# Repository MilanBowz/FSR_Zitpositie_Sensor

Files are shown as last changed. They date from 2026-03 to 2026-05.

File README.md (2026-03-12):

# FSR sensor: Zitpositie_Sensor

Piëzoresistieve (resistieve) dunnefilm druksensoren zijn varistoren (variabele weerstanden) in circuits. </br>

Wanneer de druksensor geen externe druk heeft, bevindt het circuit zich in een hoge impedantietoestand. Wanneer er externe druk op de sensor wordt uitgeoefend, neemt de weerstand af. Met behulp van een multimeter kan de weerstandswaarde direct worden afgelezen.

De weerstandswaarde verandert met de externe druk. De druk & weerstand staan in tegengestelde verhoudingen.

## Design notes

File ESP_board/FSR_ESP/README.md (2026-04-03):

# Resultaten FSR met simpele pull-down weerstand (10kE)

F: R = U/I
Rpulldown = 10kE | Rfsr (noload) > 2000 kE

## Als Rf/R2 niet ingedrukt

Vout ~= 0 V

## Als Rf/R2 ingedrukt
Vin >= Vout > 0 V 

## Testen met vaste gewichten Vin = 3.3V
Testmethode: Vcc = 3.3V altijd gewichten verwijderen voor volgend testresultaat</br>
Vout = Vcc * R0/(R0+Rs) = 3.3 * 10000/(10000+Rs)

### Sensor 2 Newton (~2kg)
Rfsr (noload) > 2000 kE

Gewicht (g) met weegschaal | Vout(min) (V) | Vout(rms) (V) | R_FSR (Ω)| voorwerp
------------------------|----------|---------|------------------------|----------|
0                       | 0        | 0 | >2000kE            | geen gewicht 
20                      | 1.44      | 1.52 | x           | glazen kurk
24                      | 2.00      | 2.08 | x          | glazen kurk + plastiek gadget
31                      | 2.24      | 2.32 | x           | glazen kurk + plastieke munt
35                      | 2.40      | 2.48 | x          | glazen kurk + plastieke munt + plastiek gadget
42                      | 2.56      | 2.64 | x          | glazen kurk + 2 plastieke munt
46                      | 2.64      | 2.72 | 3k          | glazen kurk + 2 plastieke munt + plastiek gadget
114                      | 2.72      | 2.84 | 500E         | glazen kurk + kaars 1
236                     | 2.96      | 3.04 | 300E          | glazen kurk + kaars 2
498 +20                     | 2.96      | 3.04 | 300E        | glazen kurk + kaars 3
?                    | 3.04      | 3.12 | x           | glazen kurk + max pressure human
...

Deze sensor werkt goed voor 20–500 g, maar verzadigt rond 3V (>500 g).

### Sensor 1 (0-150kg)
Rfsr (noload) > 2000 kE

Gewicht (kg) met weegschaal | Vout (V)  | R_FSR (Ω) | voorwerp
------------------------|-----------|-------------|----------|
0                       | 0         | >2000k          | geen gewicht / kurk
1.255                    | 0.036m     |  >2000k           | gymgewicht 1.25kg
2.324                    | 0.036m     | >2000k           | gymgewicht 2.5kg
3.579                    | 0.050m | >2000kE           | gymgewicht 2.5kg + 1.25
4.655                    | 0.100m | >2000k           | 2 x gymgewicht 2.5kg
5.910                    | 0.130m | >2000k          | 2 x gymgewicht 2.5kg + 1.25
26.000                    | 0.02 | 1500-1700k          | koeler  26kg </br> aan de 2000 kE grens|
... ||| metingen puur met multimeter
... ||| best > 30 kg om te meten
63.000 | x | 10k-12k | persoon x
... | x |  | persoon z
90.000                    | 3.15 | 200-450          | persoon y => max. gewicht |
...

**Vout = Vcc x R / (R + Rfsr)** </br>
2000kE : Vout ≈ 3,3/201 ≈ 0.016 V </br>
1500kE : Vout ≈ 3,3 x (10/(10 + 1500)) ≈ 0.02 V </br>
10kE : Vout ≈ 3,3 x (10/(10 + 10)) ≈ 1.5 V </br>
450E: Vout ≈ 3,3 x (10/(10+ 0,45)) ≈ 3,15 V

Deze sensor meet pas vanaf ~25 kg betrouwbaar, optimaal bereik voor 3.3V is 30–90 kg.

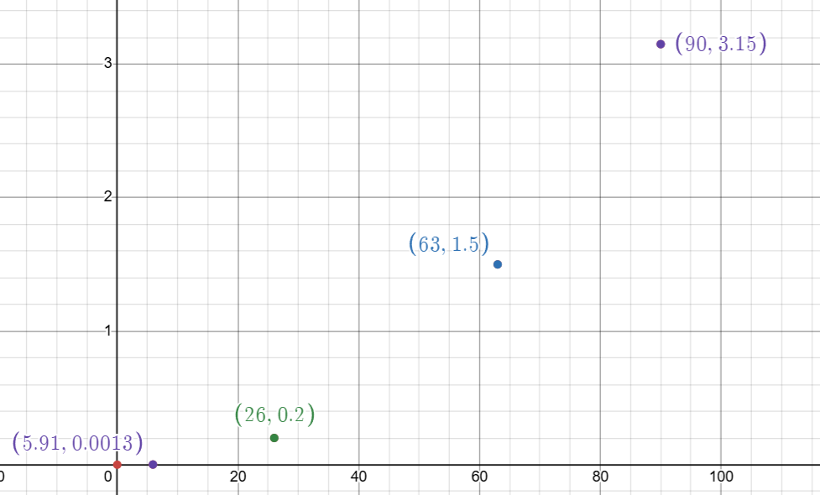
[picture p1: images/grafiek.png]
test


## Conclusies

FSR-sensoren zijn niet lineair: De weerstand daalt exponentieel met toenemende kracht, wat leidt tot een afnemende spanningsverandering bij hogere belastingen.

Dode zone bij lichte belasting – Beide sensoren vertonen vrijwel geen Vout voor gewichten onder ~10 kg (Sensor 1) of onder ~20 g (Sensor 2). Pas boven drempelwaarde treedt meetbare verandering op.

Grafiek toont typische FSR-kromme – Steile stijging in lage belasting, daarna afvlakking (verzadiging).

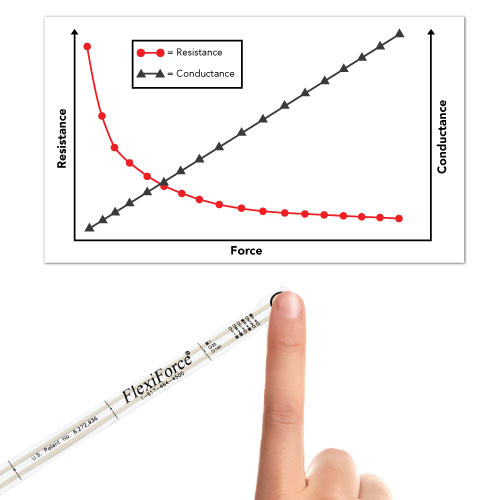
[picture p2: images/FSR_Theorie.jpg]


## Verdere stappen

1. Data doorgeven aan PC
    - Serieel (USB-UART) – Meest eenvoudig: stuur Vout-waarden als ASCII via Serial.print() naar PC.
    - ADC uitlezen (ESP32) – analoge pin, sample rate ≥ 10 Hz. (done)

2. Grafiek displayen (real-time of offline)

3. Zithouding herkennen via grafiekanalyse

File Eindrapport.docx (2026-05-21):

# Elektronische Systemen 2: FSR

Author | Milan Posman, Nick Driessen

Abstract

Dit project richt zich op het ontwikkelen van een systeem om zithouding en bewegingen op een stoel te detecteren met behulp van FSR-druksensoren. Het systeem meet de drukverdeling op de stoel om verschillende houdingen zoals rechtop zitten, onderuitgezakt zitten en verzitbewegingen te herkennen.

De FSR-sensoren worden strategisch op de stoel geplaatst en reageren op drukveranderingen tijdens het zitten. Tijdens een eerste test werd aangetoond dat het systeem onderscheid kan maken tussen verschillende zitposities en bewegingen. De sensoren werden gekalibreerd om nauwkeurige metingen mogelijk te maken.

Voor het eindproduct worden de sensoren discreet onder de stoelpoten geplaatst. De elektronica wordt in een kleine behuizing onder de stoel gemonteerd en kan op batterijen werken.

Het eindresultaat is een functioneel prototype dat real-time houdingsdetectie en bewegingsherkenning mogelijk maakt. De data kan lokaal worden weergegeven of draadloos worden doorgestuurd voor verdere analyse, met toepassingen in ergonomie en langdurige monitoring.

Content

# Intro

## Situering

De onderzoeksvraag: “Hoe kan een systeem op basis van FSR-druksensoren worden ontwikkeld en gevalideerd om zithouding (rechtop,onderuitgezakt,...) en bewegingen (verzitten , gewichtsverplaatsing,...) op een stoel te detecteren? ”

## Doelstellingen

Real-time houdingsdetectie mogelijk maken voor praktische toepassingen.

Onderscheid maken tussen verschillende zitposities.

# Materiaal & methodes

## Gebruikte technologie

- Bluetooth

## Hardware gebruikt ter ondersteuning

### Keuze sensor

Mogelijke sensoren om druk te meten:

- FSR sensor (Force Sensitive Resistor)
  - Weerstandswaarde verandert als er druk op komt
  - Goedkoop en eenvoudig te gebruiken
  - Minder nauwkeurig
  - Gebruikt voor: bedieningspanelen van medische apparatuur, op de dashboards van auto's en op de bedieningspanelen van industriële apparatuur
- Load cell
  - Zeer nauwkeurig
  - Complexer en duurder
  - Gebruikt bij weegschalen

Er is gekozen voor FSR-sensoren omdat:

- De eenvoud en lage kostprijs prioriteit hebben voor dit project.
- De lagere nauwkeurigheid is aanvaardbaar voor het detecteren van zithouding en bewegingen (discrete detectie, geen exacte gewichtsmeting nodig).
- De sensor eenvoudig kan worden uitgelezen met een microcontroller (geen extra versterker nodig).

Gebruikte FSR-sensoren:

  - FSR met 2 kg-limiet om werking makkelijk uit te testen
  - FSR van 150 kg-limiet om te gebruiken in eindproduct

### Ondersteunend materiaal

- Weerstand van 10kE om kortsluiting te voorkomen
- ESP32: microcontroller als FSR uitlezer en verzender via bluetooth.
- breadboard, jumperkabels, ... : voor het bouwen van prototypes.
- 3D printer voor FSR stabieler te kunnen testen

## Softwaretools gebruikt ter ondersteuning

- Visual Studio (PlatformIO) / Arduino IDE: programmeren en uploaden van ESP32-code.
  - BluetoothSerial.h library voor bluetoothcommunicatie op ESP32
- Thonny: visualisatie van waardes via dashboard op laptop
- Serial Monitor: debuggen van bluetooth-communicatie.

# Resultaten

## ESP32: uitlezen FSR-weerstand

FSR-sensoren zijn varistoren (variabele weerstanden) in circuits.

Wanneer de druksensor geen externe druk heeft, heeft de FSR een hoge weerstand. Wanneer er externe druk op de sensor wordt uitgeoefend, neemt de weerstand af. Met behulp van een multimeter, oscilloscoop of microcontroller kan de weerstandswaarde direct worden afgelezen.

FSR / Weerstand | ESP32 (zie afbeelding) | Multimeter-meting
FSR (Begin) | 3.3 V | Rfsr (noload) > 2000 kE Rfsr (fullload) ≃ 0 E
FSR (Einde) | GPIO34 / D34 (ADC1_CH6)
Weerstand (Einde) | GND | R = 10kE , deze weerstand is tegen kortsluiting

De weerstandswaarde verandert met de externe druk. De druk & weerstand staan in tegengestelde verhoudingen.

### Circuit zonder opamp

Voorbeeldcircuit in Multisim online (vervang potentiometer door FSR-weerstand):

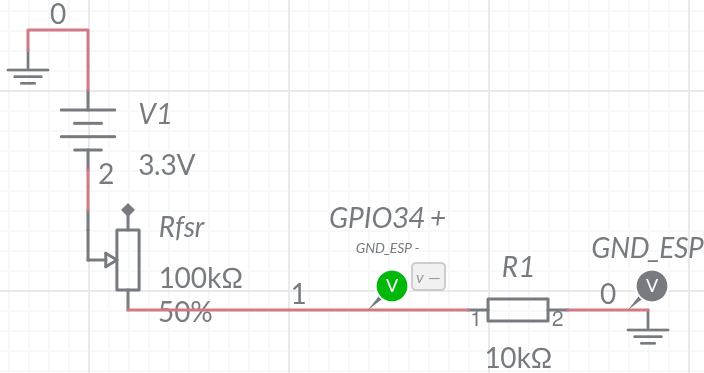
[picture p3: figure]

### Alternatief circuit met opamp: Transimpedance Amplifier

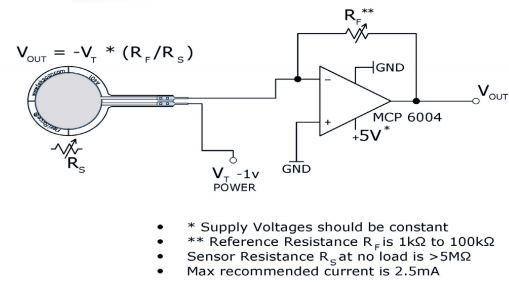
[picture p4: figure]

Een FSR-sensor met een transimpedance amplifier geeft een nauwkeuriger en meer lineaire eindmeting dan met een eenvoudige pull-downweerstand. Hierdoor is de gevoeligheid hoger en wordt de meting minder afhankelijk van variaties in de weerstand van de FSR.

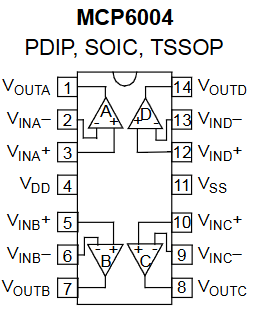
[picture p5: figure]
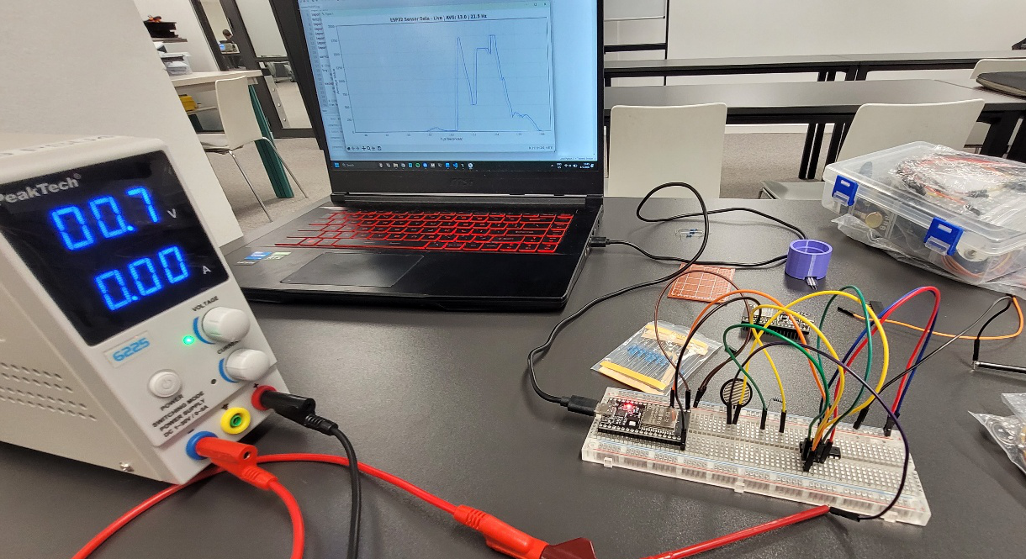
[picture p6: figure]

Nabouwen Transimpedance Amplifier met FSR sensor:

### Software

De software initialiseert de Bluetooth communicatie op een COM poort op Windows (11).

Softwarebenodigdheden:

- Arduino IDE / Visual studio code (PlatformIO)
- Blender om stabielere testopstelling te maken
- BluetoothSerial.h Arduino library
- Thonny editor voor pythoncode met:
  - matplotlib om resultaat te tonen in een grafiek
  - serial om te communiceren met de ESP32 via bluetooth

### 3D-Models

Deze modellen zijn ontworpen om veel stabielere resultaten te verkrijgen in tests door de FSR sensor vast te zetten in het groene model en een de objecten die gewogen worden op het paarse object (~ kurk) te plaatsen.

Het paarse object kan vervangen worden door een glazen kurk, maar daarvoor moet je voorzichtig zijn dat deze kurk niet te veel kan bewegen (kan voor verschillende metingen zorgen).

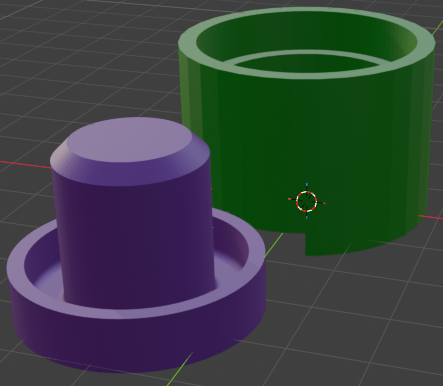
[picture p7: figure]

### Test: relatie tussen gewicht en voltage / weerstand

Deze tests werden uitgevoerd met de 3.3 V & GND van de ESP, maar de uitmeting van de voltage werd gedaan met een oscilloscoop voor Voltage en multimeter voor de weerstandsmetingen.

#### Test met 2kg FSR sensor

Het gewicht wordt hier gemeten met een keukenweegschaal.

Conclusie Sensor 2: Werkt goed tussen 20–500 g. Verzadigt rond 3 V bij belasting > 500 g.

Gewicht (g) | Vout(min) (V) | Vout(rms) (V) | R_FSR (Ω) | Object
0 | 0 | 0 | >2000kE | geen gewicht
20 | 1.44 | 1.52 | x | glazen kurk
24 | 2.00 | 2.08 | x | glazen kurk + plastiek gadget
31 | 2.24 | 2.32 | x | glazen kurk + plastieke munt
35 | 2.40 | 2.48 | x | glazen kurk + plastieke munt + plastiek gadget
42 | 2.56 | 2.64 | x | glazen kurk + 2 plastieke munt
46 | 2.64 | 2.72 | 3k | glazen kurk + 2 plastieke munt + plastiek gadget
114 | 2.72 | 2.84 | 500E | glazen kurk + kaars 1
236 | 2.96 | 3.04 | 300E | glazen kurk + kaars 2
498 +20 | 2.96 | 3.04 | 300E | glazen kurk + kaars 3
? | 3.04 | 3.12 | x | glazen kurk + max pressure human

Bij het herhaaldelijk meten van hetzelfde gewicht kunnen andere waarden optreden. Dit komt door de eigenschappen van FSR-sensoren. Deze zijn de belangrijkste om rekening mee te houden bij basisgebruik / -testen :

- Plaatsing v/h gewicht: dit beïnvloed de drukverdeling, wat een ander “path van least resistance” kan geven voor de FSR met als gevolg een andere weerstandswaarde.
- Snelheid van belasting (en ontlasting) kan meer/minder druk op de FSR zetten, wat een andere weerstandswaarde veroorzaakt.
- Belasting toevoegen op bestaande belasting t.o.v. herbeginnen met 0: bij belasting toevoegen is de weerstandsverandering kleiner dan eerst resetten naar 0.

#### Test met FSR sensor van 150kg

Het gewicht wordt hier gemeten met een weegschaal voor mensen.

Conclusie FSR 150 kg: Meet pas betrouwbaar vanaf ~25 kg.

Optimaal bereik bij 3,3 V voeding: 30–90 kg.

Gewicht (kg) | Vout (V) | R_FSR (Ω) | Object
0 | 0 | >2000k | geen gewicht / kurk
1.255 | 0.036m | | gymgewicht 1.25kg
2.324 | 0.036m | | gymgewicht 2.5kg
3.579 | 0.050m | | gymgewicht 2.5kg + 1.25
4.655 | 0.100m | | 2 x gymgewicht 2.5kg
5.910 | 0.130m | | 2 x gymgewicht 2.5kg + 1.25
26.000 | 0.02 | 1500-1700k | koeler 26kg aan de 2000 kE grens
... | | | metingen puur met multimeter best > 30 kg om te meten
63.000 | x | 10k-12k | persoon x
... | x | | persoon z
90.000 | 3.15 | 200-450 | persoon y => max. gewicht

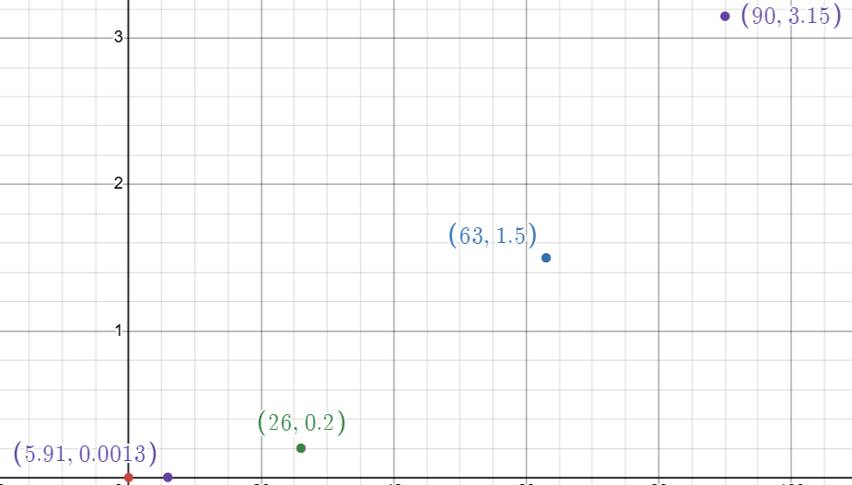
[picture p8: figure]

#### Conclusies uit testopstelling

FSR-sensoren zijn niet lineair: De weerstand daalt exponentieel met toenemende kracht, wat leidt tot een afnemende spanningsverandering bij hogere belastingen.

Dode zone bij lichte belasting – Beide sensoren vertonen vrijwel geen Vout voor gewichten onder ~10 kg (FSR 150kg) of onder ~20 g (FSR 2 kg). Pas boven drempelwaarde treedt meetbare verandering op.

Bij het herhaaldelijk meten van hetzelfde gewicht kunnen andere waarden optreden.

Deze zijn de belangrijkste om rekening mee te houden bij basisgebruik / -testen :

- Plaatsing v/h gewicht
- Snelheid van belasting (en ontlasting)
- Belasting toevoegen op bestaande belasting t.o.v. herbeginnen met 0

Grafiek toont typische FSR-kromme zoals in deze modelgrafiek:

- Steile stijging in lage belasting, daarna afvlakking (verzadiging).

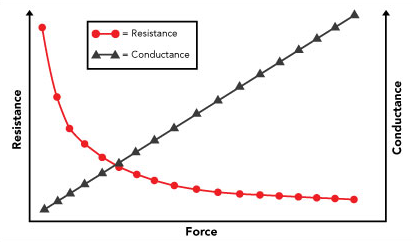
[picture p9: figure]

### Basiscode: Communicatie met PC via Bluetooth & tonen in een grafiek

De ESP32 verstuurt de gemeten sensorwaarden via Bluetooth naar een computer.

De Pythonsoftware:

- leest de seriële data uit;
- verwerkt de meetwaarden;
- toont de resultaten in real-time grafieken.

Hierdoor kunnen veranderingen in zithouding onmiddellijk zichtbaar gemaakt worden.

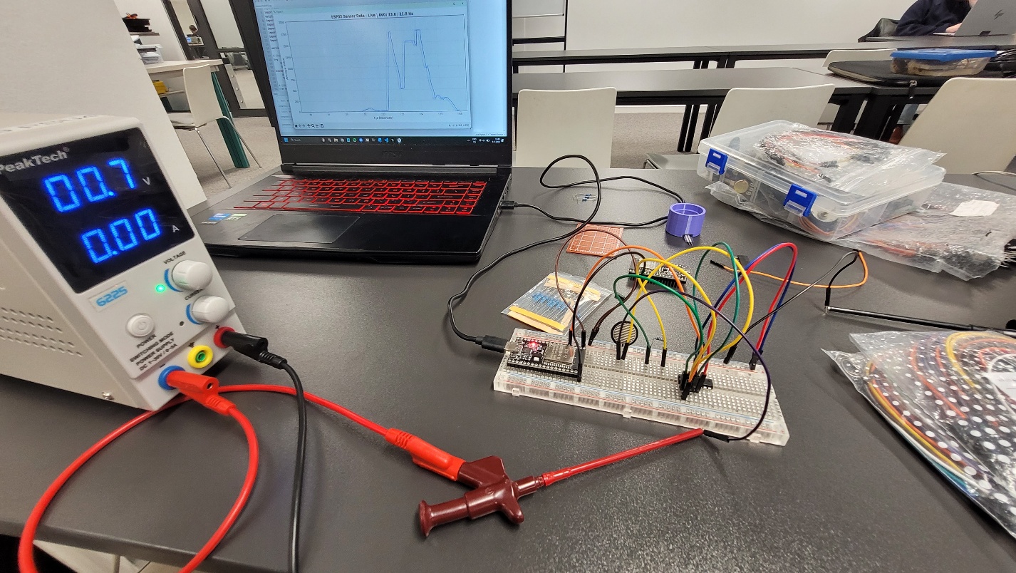
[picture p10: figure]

### Uitlezen van grafiek om zithouding & bewegingen te herkennen

Door meerdere FSR-sensoren onder een stoel te plaatsen kan de drukverdeling worden geanalyseerd.

## Mogelijke detecties

- Rechtop zitten
- Onderuitgezakt zitten
- Naar links of rechts leunen
- Verzitten
- Opstaan of gaan zitten

## Werking

Elke houding veroorzaakt een ander drukpatroon:

- meer druk achteraan → onderuitgezakt;
- ongelijke verdeling → leunen;
- snelle veranderingen → beweging.

Door deze patronen te analyseren kan het systeem houdingen herkennen.

# Mogelijke verbeteringen

## Hardware

- Meer sensoren toevoegen voor hogere nauwkeurigheid.
- Compactere behuizing ontwerpen.

## Functionaliteit

- Waarschuwingen bij slechte houding.
- Opslag van meetgegevens.

# Eindconclusie

In dit project werd een werkend prototype ontwikkeld dat zithouding en beweging detecteert met behulp van FSR-druksensoren en een ESP32-microcontroller.

Uit de experimenten bleek dat FSR-sensoren geschikt zijn voor het herkennen van drukveranderingen en houdingspatronen, ondanks hun beperkte nauwkeurigheid en niet-lineaire karakteristiek. De combinatie van een eenvoudige spanningsdeler, Bluetoothcommunicatie en real-time visualisatie maakte het mogelijk om verschillende zitposities en bewegingen te onderscheiden.

De 150 kg FSR-sensor bleek het meest geschikt voor toepassing in een stoel, aangezien deze ontworpen is voor hogere belastingen zoals het gewicht van een persoon. Hoewel de metingen variaties vertonen door drukverdeling en belastingshistoriek, zijn de resultaten voldoende betrouwbaar voor houdingsdetectie.

Het eindresultaat vormt een goede basis voor verdere ontwikkeling richting ergonomische monitoring, gezondheidsanalyse en slimme stoelsystemen.

Eindrapport Elektronische Systemen 2: Milan Posman, Nick Driessen

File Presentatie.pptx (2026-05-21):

## Elektronische Systemen FSR

## FSR sensor

Force-sensing resistors:
- Weerstand verlaagt met kracht
Intern:
- 2 geleidende lagen met daartussen
- drukgevoelig resistief materiaal

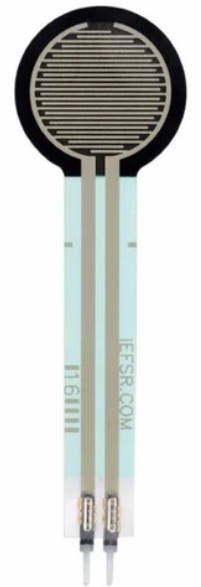
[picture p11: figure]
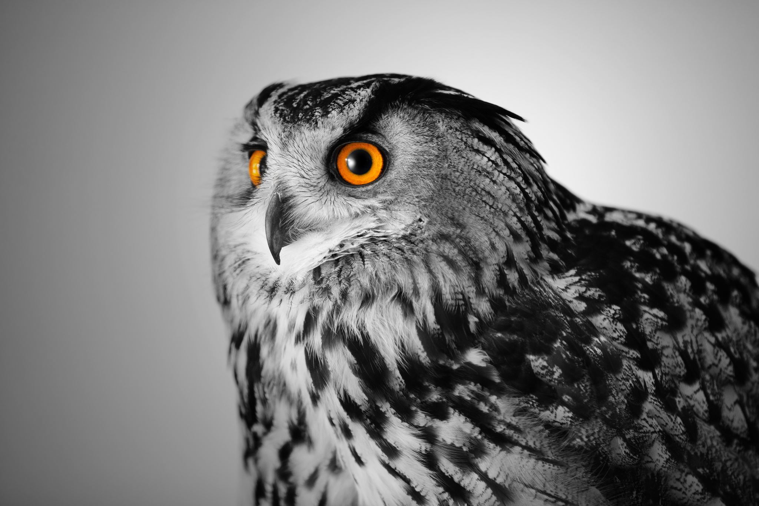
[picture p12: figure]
Black and white image of a hawk

## Onderzoeksvraag

“Hoe kan een systeem op basis van FSR-druksensoren worden ontwikkeld en gevalideerd om zithouding (rechtop,onderuitgezakt,...) en bewegingen (verzitten , gewichtsverplaatsing,...) op een stoel te detecteren? ”

## FSR-sensor met pull-down weerstand

- Gebruikt om relatie gewicht/voltage mee te testen


## FSR-sensor met pull-down weerstand

- Vergelijking met theorie

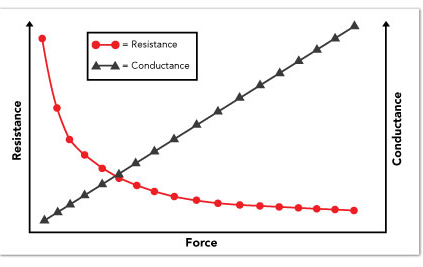
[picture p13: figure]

## Demo: FSR data tonen op laptop

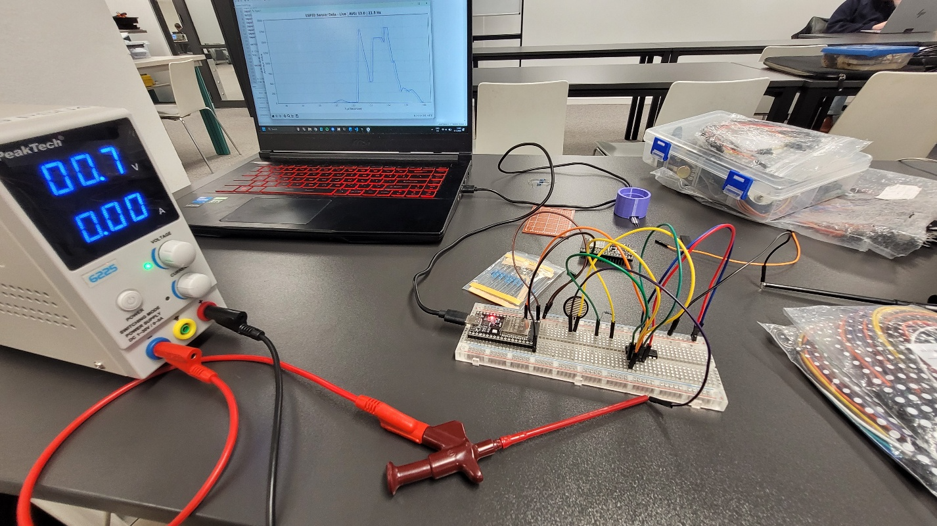
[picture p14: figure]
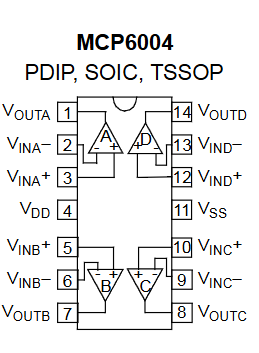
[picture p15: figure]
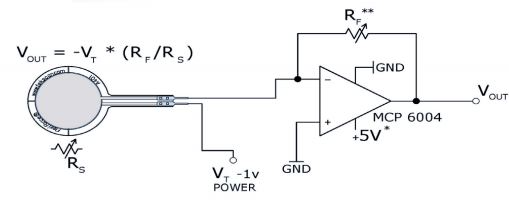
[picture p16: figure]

## Wat geleerd ? / uitdagingen

- Kiezen voor tijdbesteding / prioriteiten
- Zelfstandig taken opstellen
- Vertrouwbaar testen uitvoeren
  - Opstelling / 3D print

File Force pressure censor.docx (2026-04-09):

Sensorproject – Zitpositie detectie

1. Wat meten we en hoe

We willen meten of iemand correct op een stoel zit.
Dit doen we door de druk (gewicht) op de stoel te meten.

- We meten krachten tot ongeveer 150 kg
- De sensor zit onder het zitvlak
- Als iemand recht zit, is de druk gelijk verdeeld
- Als iemand scheef of onderuit zit, verandert de druk

Zo kunnen we zien of de zithouding goed is of niet.

2. Mogelijke sensoren

Er zijn verschillende sensoren om druk te meten:

- FSR sensor (Force Sensitive Resistor)
  - Weerstand verandert als er druk op komt
  - Goedkoop en eenvoudig te gebruiken
  - Minder nauwkeurig
- Load cell
  - Zeer nauwkeurig
  - Complexer en duurder

Wij gebruiken een FSR sensor van 150 kg, omdat die eenvoudiger is en voldoende voor ons doel.

Signaalverwerking

De FSR sensor werkt als een variabele weerstand:

- Meer druk → lagere weerstand
- Minder druk → hogere weerstand

We meten dit met een spanningsdeler:

- FSR + vaste weerstand
- De spanning ertussen gaat naar de ESP32

De ESP32 zet deze spanning om naar een digitale waarde.

3. Prototype

Schakeling

- FSR in serie met een vaste weerstand
- Middelpunt → analoge pin van de ESP32

Zo kunnen we de druk aflezen.

Testopstelling

We testen door:

- Gewichten op de sensor te plaatsen
- Op de stoel te zitten in verschillende houdingen

Bijvoorbeeld:

- Recht zitten → normale waarde
- Scheef zitten → andere waarde

Besluit

We gebruiken een FSR sensor met een ESP32 om druk te meten.
Dit is een eenvoudige oplossing die goed genoeg is om zithouding te detecteren, ook al is ze minder nauwkeurig dan een load cell.

Lab gewicht meten:

# Resultaten FSR met simpele pull-down weerstand (10kE)

Vout is de weerstand over R=10kE in serie met Rfsr

F: R = U/I

Rpulldown = 10kE | Rfsr (noload) > 2000 kE

## Als Rf/R2 niet ingedrukt

Vout ~= 0 V

## Als Rf/R2 ingedrukt

Vin >= Vout > 0 V

## Testen met vaste gewichten Vin = 3.3V

Testmethode: Vcc = 3.3V altijd gewichten verwijderen voor volgend testresultaat</br>

Vout = Vcc * R0/(R0+Rs) = 3.3 * 10000/(10000+Rs)

### Sensor 2 Newton (~2kg)

Rfsr (noload) > 2000 kE

Gewicht (g) met weegschaal | Vout(min) (V) | Vout(rms) (V) | R_FSR (Ω)| voorwerp

0 | 0 | 0 | >2000kE | geen gewicht

20 | 1.44 | 1.52 | x | glazen kurk

24 | 2.00 | 2.08 | x | glazen kurk + plastiek gadget

31 | 2.24 | 2.32 | x | glazen kurk + plastieke munt

35 | 2.40 | 2.48 | x | glazen kurk + plastieke munt + plastiek gadget

42 | 2.56 | 2.64 | x | glazen kurk + 2 plastieke munt

46 | 2.64 | 2.72 | 3k | glazen kurk + 2 plastieke munt + plastiek gadget

114 | 2.72 | 2.84 | 500E | glazen kurk + kaars 1

236 | 2.96 | 3.04 | 300E | glazen kurk + kaars 2

498 +20 | 2.96 | 3.04 | 300E | glazen kurk + kaars 3

? | 3.04 | 3.12 | x | glazen kurk + max pressure human

Deze sensor werkt goed voor 20–500 g, maar verzadigt rond 3V (>500 g).

### Sensor 1 (0-150kg)

Rfsr (noload) > 2000 kE

Gewicht (kg) met weegschaal | Vout (V) | R_FSR (Ω) | voorwerp

0 | 0 | >2000k | geen gewicht / kurk

1.255 | 0.036m | >2000k | gymgewicht 1.25kg

2.324 | 0.036m | >2000k | gymgewicht 2.5kg

3.579 | 0.050m | >2000kE | gymgewicht 2.5kg + 1.25

4.655 | 0.100m | >2000k | 2 x gymgewicht 2.5kg

5.910 | 0.130m | >2000k | 2 x gymgewicht 2.5kg + 1.25

26.000 | 0.02 | 1500-1700k | koeler 26kg </br> aan de 2000 kE grens|

... ||| metingen puur met multimeter

... ||| best > 30 kg om te meten

63.000 | x | 10k-12k | persoon x

... | x | | persoon z

90.000 | 3.15 | 200-450 | persoon y => max. gewicht |

**Vout = Vcc x R / (R + Rfsr)** </br>

2000kE : Vout ≈ 3,3/201 ≈ 0.016 V </br>

1500kE : Vout ≈ 3,3 x (10/(10 + 1500)) ≈ 0.02 V </br>

10kE : Vout ≈ 3,3 x (10/(10 + 10)) ≈ 1.5 V </br>

450E: Vout ≈ 3,3 x (10/(10+ 0,45)) ≈ 3,15 V

Deze sensor meet pas vanaf ~25 kg betrouwbaar, optimaal bereik voor 3.3V is 30–90 kg.


X = Gewicht in kg

Y = Voltage over R=10kE (Vout)

## Conclusies

FSR-sensoren zijn niet lineair: De weerstand daalt exponentieel met toenemende kracht, wat leidt tot een afnemende spanningsverandering bij hogere belastingen.

Dode zone bij lichte belasting: Beide sensoren vertonen vrijwel geen Vout voor gewichten onder ~10 kg (Sensor 1) of onder ~20 g (Sensor 2). Pas boven drempelwaarde treedt meetbare verandering op.

Grafiek toont typische FSR-kromme – Steile stijging in lage belasting, daarna afvlakking (verzadiging).

## Verdere stappen

1. Data doorgeven aan PC

- Serieel (USB-UART) – Meest eenvoudig: stuur Vout-waarden als ASCII via Serial.print() naar PC.

- ADC uitlezen (ESP32) – analoge pin, sample rate ≥ 10 Hz. (done)

2. Grafiek displayen (real-time of offline)

3. Zithouding herkennen via grafiekanalyse

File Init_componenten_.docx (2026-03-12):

Componenten:

- FSR-sensor: FSR02
- FSR-sensor: 0-150kg

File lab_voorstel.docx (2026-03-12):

Projectvoorstel: Drukgevoelige Zitpositie Sensor

1. Wat willen we meten?

We willen de drukverdeling op een stoel meten om de zithouding (rechtop vs. onderuitgezakt) te detecteren. Door de druk links en rechts te vergelijken, kunnen we afwijkingen vaststellen.

2. Welk sensorprincipe passen we toe?

We gebruiken twee FSR-sensoren (voorbeeld uit de link). Hun weerstand verandert naarmate de druk toeneemt. Deze weerstandsverandering zetten we om in een spanning.

3. Link met de vakinhoud?

Dit project past meerdere concepten toe:

Sensoren: De FSR zet fysieke druk om in een elektrisch signaal.

Rekstrookjes: weerstandsverandering door mechanische vervorming.

Brugschakeling: We plaatsen de sensoren in een Wheatstone-brug voor nauwkeurige meting.

Spanningsregelaar: Een regelaar zorgt voor de stabiele voeding die de sensor nodig heeft.

4. Huidig TRL-niveau?

TRL 2 (Technology Concept Formulated) . Het concept is bedacht, maar nog niet getest.

5. Te bereiken TRL-niveau?

TRL 4 (Component Validation in Laboratory Environment) . De sensoren worden in een labomgeving opgebouwd en getest.

6. Welke stappen nemen we?

Componenten: Twee FSR's, weerstanden, spanningsregelaar, breadboard en multimeter aanschaffen.

Ontwerp: Schema van de Wheatstone-brug met twee FSR's tekenen.

Bouw: Circuit opbouwen op breadboard met de spanningsregelaar.

Kalibratie: Sensorrespons meten door bekende gewichten te plaatsen.

Test: Ongelijkmatige druk uitoefenen (simulatie scheve zit) en het verschil meten.

Rapport: Bevindingen documenteren als bewijs van TRL 4.

Voorbeeld:

https://www.amazon.com.be/-/en/Sensitive-Resistance-Pressure-Resistor-Diameter/dp/B07PY443HS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

Milan Posman

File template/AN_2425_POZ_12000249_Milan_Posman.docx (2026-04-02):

# Project Onderzoek

Author | Milan Posman

Abstract

Dit project richt zich op het ontwikkelen van een communicatiesysteem op basis van LoRa E220-900T22D-modules, waarbij een microcontroller (ESP32,...) als zender en een Raspberry Pi 5 als ontvanger. Naast de configuratie en integratie van de LoRa-modules worden ook een NEO-6M GPS-ontvanger, DS18B20 temperatuursensor en een LDR toegepast.

De LoRa-communicatie is opgezet via UART met een baudrate van 9600 bps, waarbij M0 en M1 IO worden gebruikt om de E220-900T22D-module te kunnen configureren en gebruiken om data te verzenden en ontvangen. Met een 15 cm LoRa-gluestickantenne werd tijdens een veldtest een betrouwbaar maximaal bereik van 1,1 km gerealiseerd. Bij de configuratie wordt onder andere adressen, frequentiekanaal (868 MHz) en de transmissiemodus ingesteld.

Voor het eindproduct zijn alle componenten geïntegreerd in een behuizing. De verzender moet in een regenbestandige behuizing gesoldeerd op een gaatjesprint met batterijvoeding om buiten te kunnen fuctioneren. De ontvanger moet in een grote behuizing gevoedt door netstroom.

Het eindresultaat is een volledig functioneel prototype dat stabiele LoRa-communicatie, GPS-locatiebepaling, lichtintensiteit- en temperatuurmetingen combineert om te tonen in een dashboard en LCD dat met verdere iteraties online beschikbaar kan worden gemaakt,... .

Content

# Intro

## Situering

Dit project is voor het verkennen van goedkope draadloze IoT-communicatie, waarbij long-range datatransmissie centraal staat. LoRa-technologie wordt gebruikt om sensorwaarden over afstanden groter dan 1 km betrouwbaar door te sturen.

De onderzoeksvraag:

"Hoe kan een betrouwbaar long-range IoT-communicatiesysteem worden gerealiseerd met LoRa-technologie, waarbij (sensor)gegevens over afstanden groter dan 1 km worden verzonden?"

## Doelstellingen

Het doel van deze opdracht is het realiseren van een werkend long-range communicatiesysteem met LoRa-technologie. In de beginfase kozen we de benodigde componenten (LoRa-modules, zender, ontvanger, sensoren, antenne, ...).

De opdracht richt zich op:

- Het configureren en testen van de LoRa E220-modules.

- Het integreren van de sensoren (GPS-module (NEO-6M), temperatuursensor (DS18B20) en LDR).

- Het bouwen van een afgewerkt systeem door alle onderdelen in een passende behuizing te plaatsen.

- Het uitvoeren van praktijktests om bereik en betrouwbaarheid te evalueren.

Het uiteindelijke doel is een stabiel en volledig functioneel communicatiesysteem dat langeafstandsdata kan verzenden en ontvangen.

# Materiaal en methodes

## Gebruikte technologie

- LoRa (Long Range): draadloze communicatietechnologie voor lage datasnelheden over grote afstanden.

- UART / I2C / OneWire: communicatiestandaarden voor respectievelijk LoRa, LCD en temperatuursensor.

## Hardwaretools gebruikt ter ondersteuning

- Ebyte E220-900T22D: LoRa-transceivermodule gebaseerd op de LLCC68-chip.

- ESP32: microcontroller als verzender, met meerdere UART-poorten en laag energieverbruik.

- Raspberry Pi 5: single-board computer als ontvanger en data-verwerker.

- Neo-6M / NEO-M8N GPS Module: ontvangst van locatiegegevens.

- LDR (Light Dependent Resistor): meting lichtintensiteit

- DS18B20 Temperatuursensor: digitale temperatuursensor voor externe omgevingstemperatuur.

- Gaatjesprint, kabels, soldeerstation en behuizing : voor het bouwen van prototypes.

- Multimeter om correcte verbinding, kortsluitingen, ... te meten

## Softwaretools gebruikt ter ondersteuning

- Visual Studio (PlatformIO) / Arduino IDE: programmeren en uploaden van ESP32-code.

- Node-RED: visualisatie en besturing via dashboard van Raspberry Pi 5.

- Serial Monitor: debuggen van UART-communicatie.

- Ebyte Configuration Tool: controleren en configureren van LoRa-modules.

# Resultaten

## Verzender: FIXED_TRANSMISSION & E220-900T22D

Het verkennen van de E220-module en LoRa-technologie biedt een breed inzicht in de mogelijkheden van LoRa-communicatie. Dit hoofdstuk beschrijft de configuratie, werking en toepassing van de EBYTE LoRa E220-module in combinatie met de Wemos D1 Mini Pro als verzender en ESP32 als ontvanger.

De focus ligt op Fixed Transmission binnen het 868 MHz ISM-spectrum. Bij Fixed Transmission wordt elk bericht verzonden met een expliciet bestemmingsadres en kanaal.

### 1.1.1 GPIO -- Long range signal -- E220-900T22D

LoRa E220 | ESP32 | Wemos D1 Mini Pro | Opmerkingen
M0 | 21 / D21 | D7 | Normale modus (GND) / Configuratie modus (+3.3V)
M1 | 19 / D19 | D6 | Normale modus (GND) / Configuratie modus (+3.3V)
TX | RX2 / D16 | D2 | Communicatie UART
RX | TX2 / D17 | D1 | Communicatie UART
AUX | AUX: D22/23 | D5 | Busy status E220
VCC | 3.3 V - 5 V | 5 V | Voeding
GND | GND | GND | Aarde

Voorbeeldcode met FT_FIXED_TRANSMISSION zie: ```/Sender/Wemos_sendFixedTransmission.ino``` & ```Receiver/ESP32_receiveFixedTransmission/ESP32_receiveFixedTransmission.ino```

### 1.1.2 Software

De software initialiseert de UART-communicatie op 9600 bps en configureert de LoRa-module via AT-achtige commando’s die door de library worden afgehandeld.

Softwarebenodigdheden:

- Arduino IDE / Visual studio code (PlatformIO)

- LoRa_E220 Arduino library

- SoftwareSerial (voor Wemos D1 Mini Pro)

### 1.1.3 Configuratiemogelijkheden

Adressering

Binnen het LoRa E220-systeem beschikt elke module over een uniek logisch adres, bestaande uit twee delen:

- ADDH (Address High byte) +

- ADDL (Address Low byte)

Samen vormen deze bytes het node-adres ADDH + ADDL waarmee modules elkaar kunnen identificeren binnen een netwerk.

Adres van de zender

In deze configuratie werkt de Wemos D1 Mini Pro als zender:

- configuration.ADDH = 0x00;

- configuration.ADDL = 0x03 ;

Het volledige adres van de zender is daarmee 0x0003. Dit adres wordt intern gebruikt door de LoRa-module om de herkomst van verzonden berichten te identificeren.

Het zenderadres wordt niet meegegeven bij fixed transmissie, maar moet wel uniek zijn binnen het netwerk.

Adres van de ontvanger (Destination)

De ontvanger is geconfigureerd met:

- configuration.ADDH = 0x00 ;

- configuration.ADDL = 0x02 ;

Dit resulteert in het adres 0x0002. In de code van de verzender wordt dit aangeduid met:

``` #define DESTINATION_ADDL 2 ```

Bij Fixed Transmission wordt het bestemmingsadres expliciet opgenomen in elk verzonden bericht. Hierdoor accepteert uitsluitend de LoRa-module met adres 0x0002 het bericht; andere modules op hetzelfde kanaal negeren deze transmissie.

Relatie tussen zender en ontvanger

Samengevat:

- Zenderadres: 3 (0x0003)

- Bestemmingsadres: 2 (0x0002)

De zender (3) verstuurt data gericht naar de ontvanger (2) op een vast kanaal. Deze peer-to-peer-communicatie voorkomt dat andere nodes binnen hetzelfde frequentiekanaal de data verwerken.

Deze adresseringsmethode is essentieel voor schaalbare LoRa-netwerken waarin meerdere nodes gelijktijdig actief zijn zonder onderlinge interferentie.

Dat betekent dat enkel de ontvanger met een specifiek adres het bericht kan ontvangen en dus de andere apparaten geen tijd verspillen met onnodige berichten te ontvangen.

Kanaal en frequentie

Men gebruikt in de code:

- Kanaal: ```configuration.CHAN = 0x12```

- Frequentieband = basisfrequentie & kanaal ```850(.125) MHz + 0x12 MHz = 868(.125) MHz```

Het kanaal bepaalt de exacte frequentie binnen de toegestane ISM-band. Bij Fixed Transmission kan de channel voor een verzender en onvanger verschillen. De ontvanger kan bijvoorbeeld ```configuration.CHAN = 0x18;``` worden, terwijl de verzender 0x12 blijft.

Men moet deze code in de verzender als gevolg ook veranderen:

``` e220ttl.sendFixedMessage(0, DESTINATION_ADDL, 0x18, msg); ```

De functie ```e220ttl.sendFixedMessage()``` verzendt een bericht naar module met een specifiek adres en kanaal.

### 1.1.4 Algemene configuratiemogelijkheden

Transmission Mode: ```FT_FIXED_TRANSMISSION```

Ervoor zorgen dat Fixed Transmission geactiveert wordt in de module

RSSI (Received Signal Strength Indicator): ```DISABLED```

RSSI voegt extra informatie toe aan ontvangen berichten over de signaalsterkte. In deze configuratie is RSSI uitgeschakeld omdat:

- De focus ligt op basiscommunicatie en stabiliteit.

- Extra data-overhead wordt vermeden.

- Indien signaalkwaliteit of bereik in detail moet worden geëvalueerd, kan RSSI worden ingeschakeld voor onderzoeksdoeleinden.

LBT (Listen Before Talk): ```DISABLED```

LBT zorgt ervoor dat de module eerst controleert of het kanaal vrij is voordat er wordt uitgezonden. In dit onderzoek is LBT uitgeschakeld omdat:

- Het netwerk bestaat uit een beperkt aantal bekende nodes (4-6 verzenders, 1 ontvanger).

- Kanaalcongestie niet wordt verwacht. Continue en voorspelbare transmissie wordt verwacht.

WOR-periode (Wake-On-Radio) : ```2000 ms```

WOR bepaalt het interval waarin de module uit een laagvermogensmodus ontwaakt om te controleren op inkomende data.

WOR is met name enkel relevant voor batterijgevoede ontvangers en sinds enkel verzenders batterijgevoed worden kan dit standaard blijven.

### 1.1.5 Na configuratie

Na configuratie permanent opgeslagen wordt in het interne geheugen van de module wordt vervolgens:

- Bij het opstarten een testbericht verzonden.
- Worden elke 5 seconden berichten verzonden met een tijdstempel. Interessant voor te zien of er berichten verloren geraken.
- Kunnen handmatige berichten via de seriële monitor van de Wemos worden ingevoerd en verzonden.

## Prototype verzender 1: ESP32

### 1.1.6 Componenten

1. Gaatjesprint 50 * 70 mm

2. Microcontroller: ESP32

3. Stijve geleidende draad en jumperkabels

4. LoRa communicatie LoRa-module: E220

5. Multimeter om correcte verbinding en kortsluitingen te meten

6. Soldeerstation en bijhorende hulpmiddelen

### 1.1.7 Werkwijze: prototype 1 & 2

1. Solderen van female pinheaders

1. Eerst moet worden bepaald waar elk component wordt aangesloten aan de hand van het schema.
2. De soldering start bij de microcontroller, gevolgd door de LoRa-module.
3. Elke verbinding gecontroleerd met een multimeter om correcte verbinding en het ontbreken van kortsluitingen te verifiëren.

2. Bedrading met stijve geleidbare draad, begin met de aansluiting van Vcc & GND

3. Controle verbinding

Na het solderen wordt de verbinding tweemaal gecontroleerd. De controle focust zowel op het vermijden van kortsluitingen als op het garanderen van een betrouwbare elektrische verbinding.

1. ~ 5 minuten na het solderen
2. ~ 24 uur na het solderen, om mogelijke veranderingen van warmte of mechanische spanning te detecteren.

4. Extra isolatie

- Ter bescherming tegen waterschade en het risico op kortsluiting wordt een isolerende coating aangebracht.
- Tijdens dit proces worden gevoelige componenten tijdelijk verwijderd om beschadiging te voorkomen.

## Verzender prototype 2: Wemos D1 mini pro

### 1.1.8 Werkwijze

De werkwijze voor prototype 2 is identiek aan die van prototype 1, met als voornaamste verschil dat de ESP32 is vervangen door een Wemos D1 mini Pro. Daarnaast wordt gebruikgemaakt van een kleinere gaatjesprint met afmetingen van 40 × 60 mm.

Deze aanpassing heeft als doel te evalueren of het ontwerp kan worden verkleind naar een compacter formaat, zonder negatieve impact op de functionaliteit, betrouwbaarheid of soldeerkwaliteit van het prototype.

### 1.1.9 Conclusie

Uit prototype 2 blijkt dat het technisch mogelijk is om het ontwerp verder te verkleinen naar 40 × 60 mm.

Bij dit formaat wordt de integratie van andere componenten, zoals sensoren en batterij veel complexer. De beperkte beschikbare ruimte vereist een zeer doordachte plaatsing en soldering, waarbij manuele assemblage steeds moeilijker wordt.

Om deze reden is dit compact ontwerp beter geschikt voor machinale ontwikkeling, waar hogere precisie kunnen worden gegarandeerd.

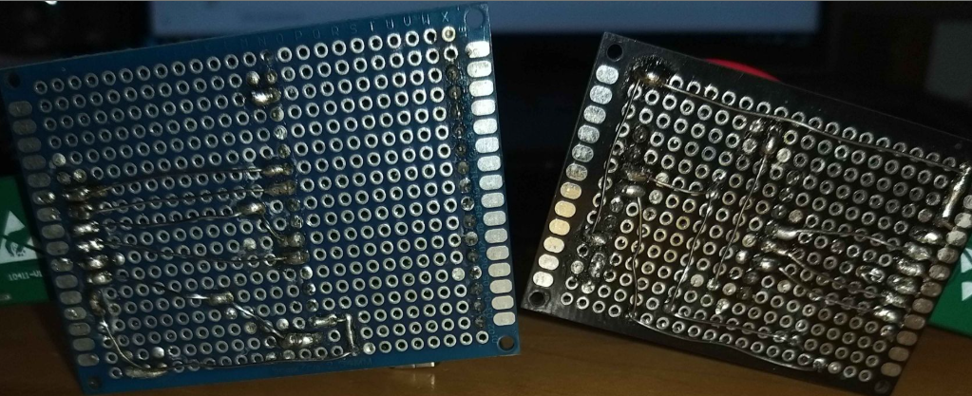
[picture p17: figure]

Solderen prototype 1 & 2: achterkant

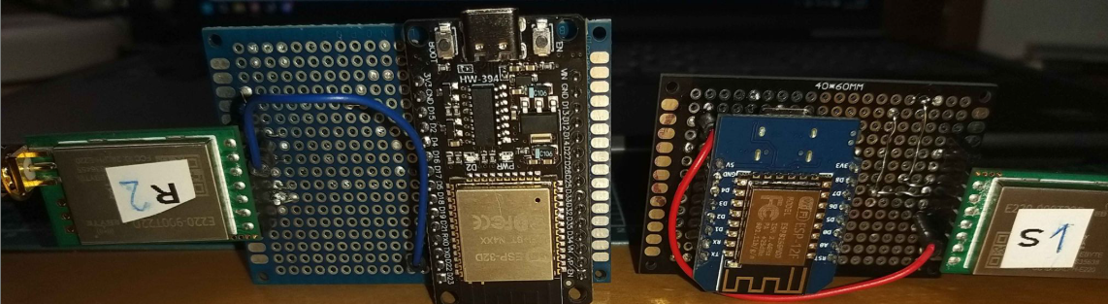
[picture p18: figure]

Solderen prototype 1 & 2: voorkant

Om deze 2 prototypes te testen kan het hoofdstuk FT_FIXED_TRANSMISSION geraadpleegd worden.

## Ontvanger (Raspberry Pi 5)

De Raspberry Pi 5 wordt in deze opstelling gebruikt als centrale ontvanger voor draadloze communicatie via de EBYTE LoRa E220-module. Naast het ontvangen van LoRa-berichten vervult de Raspberry Pi ook een verwerkings- en gebruikersinterface geprogrammeerd via Node-RED.

### 1.1.10 GPIO

De communicatie tussen de Raspberry Pi 5 en de LoRa E220-module verloopt via UART. Volgende tabel geeft een overzicht van de gebruikte GPIO-aansluitingen en hun functie.

LoRa E220 pin | Raspberry Pi 5 aansluiting | Opmerkingen (/dev/ttyAMA0)
VCC | 3.3 V – 5 V | Voeding
GND | GND | Aarde
TX | UART RX (GPIO 15) | UART-communicatie
RX | UART TX (GPIO 14) | UART-communicatie
M0 | GND / GPIO 21 | Normale modus (GND) / Configuratiemodus (+3.3 V)
M1 | GND / GPIO 20 | Normale modus (GND) / Configuratiemodus (+3.3 V)
AUX | GPIO 18 | Busy/statussignaal van de E220-module

Een LCD-scherm wordt aangesloten via het I2C-protocol om ontvangen gegevens visueel weer te geven.

LCD pin | Raspberry Pi 5 aansluiting | Opmerkingen
SCL | SCL (GPIO 3) | I2C communicatie: Serial Clock
SDA | SDA (GPIO 2) | I2C communicatie: Serial Data
GND | GND | Aarde
VCC | 5 V | Voeding

Een drukknop wordt gebruikt om de Raspberry Pi veilig in en uit te schakelen. Daarnaast geeft een LED de operationele status van het systeem en NodeRed weer.

Component | Raspberry Pi 5 aansluiting | Opmerkingen
LED + | GPIO 18 | Statusindicatie: Pi actief en Node-RED operationeel (met serieweerstand)
LED − | GND | Aarde LED
Button 0 | GPIO 17 & J2 | GPIO x voor software-shutdown, J2 voor hardware power control
Button 1 | GND (J2 / overige GND) | Aarde knop (normaal open drukknop)

### 1.1.11 Enable UART & I2C

Om seriële communicatie via UART en I2C mogelijk te maken, dienen deze geactiveerd te worden via de `Interfacing Options` van raspi-config.

Open de Raspberry pi configuratie met het commando ``` sudo raspi-config```

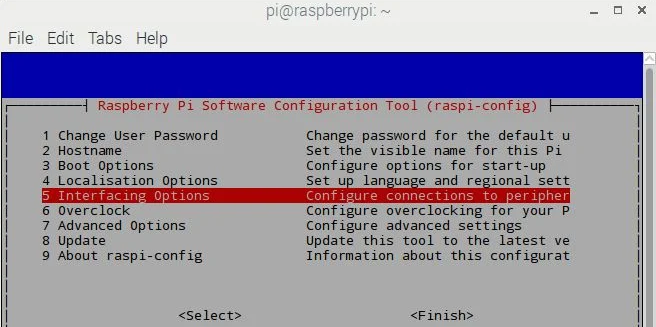
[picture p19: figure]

Configureer de volgende opties:

- Serial Port

- Login shell over serial: Disabled

- Serial port hardware: Enabled

- I2C: Enabled

Bevestig de wijzigingen en herstart de Raspberry Pi.

### 1.1.12 Controle activatie UART via configuratiebestand

Om te testen dat seriële communicatie via UART geactiveerd is waardoor seriële communicatie via `/dev/ttyAMA0` mogelijk wordt, kan in dit configuratiebestand van de Raspberry Pi gekeken worden.

Aan het einde van `/boot/firmware/config.txt` zal de volgende configuratie aanwezig zijn:

```

[all]

dtparam=uart0=on

```

### 1.1.13 Autostart Node-RED

Om Node-RED automatisch te starten bij het opstarten van de Raspberry Pi en het dashboard fullscreen weer te geven, wordt gebruikgemaakt van een shellscript en een `.desktop`-bestand.

Shellscript (`nodered_autostart.sh`)

```

sudo systemctl stop nodered.service;

sudo systemctl start nodered.service;

sleep 5;

chromium --kiosk --password-store=basic "http://127.0.0.1:1880/dashboard"; # open in browser

```

De eerste twee commando’s herstarten Node-RED. Dit zorgt ervoor dat Node-RED zich steeds in een bekende en stabiele toestand bevindt bij het opstarten van het systeem.

Vervolgens wordt er vijf seconden gewacht om te garanderen dat Node-RED volledig is opgestart voordat het dashboard wordt geopend.

Ten slotte wordt Chromium gestart in kioskmodus, waarbij het Node-RED dashboard automatisch fullscreen op het aangesloten beeldscherm wordt weergegeven. Hierdoor is het systeem geschikt voor visualisatie- of monitoringtoepassingen.

Autostart-configuratie (`~/.config/autostart/red.desktop`)

```

[Desktop Entry]

Type=Application

Name=Node-RED Autostart

Exec=<script-location>/nodered_autostart.sh

X-GNOME-Autostart-enabled=true"http://127.0.0.1:1880";

```

Het .desktop-bestand in `~/.config/autostart/` zorgt ervoor dat het shellscript automatisch wordt uitgevoerd zodra de grafische desktopomgeving van de Raspberry Pi is geladen.

De parameter `Exec` verwijst naar de locatie van het shellscript `nodered_autostart.sh`, terwijl `X-GNOME-Autostart-enabled=true` aangeeft dat deze applicatie automatisch wordt opgestart.

### 1.1.14 Controle van autostart

```

chmod +x red.desktop;

sudo reboot;

```

Door het .desktop-bestand uitvoerbaar te maken en het systeem te herstarten, kan de correcte werking van de autostart worden gevalideerd.

Na het herstarten start Node-RED automatisch en wordt het dashboard automatisch in kioskmodus weergegeven.

### 1.1.15 Test Configuratie & Communicatie met E220 (python)

Voor de configuratie en werking van de LoRa-module wordt UART gebruikt in combinatie met M0, M1 en AUX. Door deze signalen correct aan te sturen kan dynamisch worden gewisseld tussen configuratiemodus (AT-commands) en normale transmissiemodus.

Om het wisselen tussen configuratie- en transmissiemodus mogelijk te maken, worden M0 & M1 softwarematig aangestuurd. AUX wordt gebruikt als indicator wanneer de module bezig is.

Voor meer informatie zie ook handleiding E220-xxxTxxx : 5.2 AUX Timing, 7. AT Commands

Pseudocode voor configuratie van receiver:

1. M0 & M1 : 3.3 V / HIGH ( Configuration / Sleep mode )

2. Wacht tot AUX uitgang = HIGH ( E220 niet bezig )

3. Verzend @-command ( UART )

4. Wacht tot AUX = HIGH

5. Lees alles wat E220 beantwoordt ( UART )

6. Stap 3 OF exit config M0 & M1 : GND ( Transmission mode )

7. Wacht tot AUX = HIGH

8. Ontvang LoRa berichten …

Het volledig Python-codevoorbeeld voor de ontvanger is terug te vinden in:

`Receiver/reset_config_pi5/config+reset.py`

Belangrijke functies in de code:

- `enter_at_mode()` / `exit_at_mode()`

Wisselen tussen configuratie- en transmissiemodus via GPIO. (at-mode = configuratiemodus)

- `wait_aux_ready()`

Blokkering wanneer de module bezig is om timingproblemen te vermijden.

- `send_at_command()`

Verzenden en uitlezen van AT-commando’s via UART in configuratiemodus.

- `receive_data()`

Uitlezen van ontvangen in transmissiemodus.

## Eindproduct ontvanger: Raspberry Pi met Node-RED

### 1.1.16 Installatie en gebruik van Node-RED

Voor de installatie van Node-RED wordt de officiële gids gevolgd: Node-RED Getting Started – Local (https://nodered.org/docs/getting-started/local).

Met een Linux-command (Raspberry Pi,...) kan Node-RED geïnstalleerd worden:

```sudo npm install -g --unsafe-perm node-red``` # In Windows wordt sudo niet gebruikt.

Na installatie kan Node-RED gestart worden via: ```node-red```

Node-RED kan projecten (flows) exporteren in het .json-formaat, deze kunnen worden geïmporteerd door anderen. Indien het apparaat zich in een netwerk bevindt, kunnen anderen via de website van Node-RED toegang krijgen tot de flows voor controle of aanpassingen.

### 1.1.17 Communicatie met LoRa-module via UART

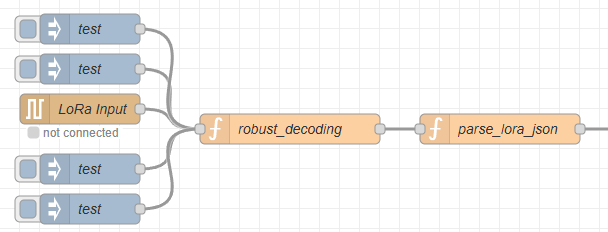
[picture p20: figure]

UART Communicatie `LoRa Input`

Voor de communicatie tussen Node-RED en de E220-module wordt een `Serial In` node gebruikt. Deze node leest inkomende gegevens via UART van de LoRa-module.

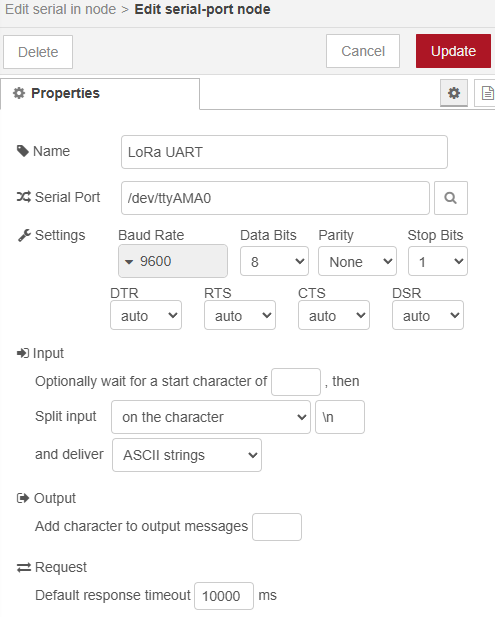
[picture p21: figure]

De `seriële poort` wordt `/dev/ttyAMA0` en is de UART-interface via de GPIO pinnen van de Raspberry Pi 5.

Aangezien de Raspberry Pi 5 meerdere UART-poorten heeft, kan een andere seriële poort geselecteerd worden indien er geen data wordt ontvangen. `/boot/firmware/config.txt` kan geraadpleegd worden om de correcte poort te vinden.

`Baud-rate 9600` is vastgelegd door de E220-module.

`Data Bits: 8` is de standaardinstelling voor UART communicatie.

`Geen pariteitscontrole` is de standaardinstelling voor UART communicatie.

`Stop Bits: 1` is de standaardinstelling voor UART communicatie.

UART-data omvormen `Robust decoding`

Voor het omvormen van UART-data wordt een `function` node gebruikt. Deze node zet bytegegevens om naar een leesbaar tekstformaat, zodat verdere verwerking en visualisatie mogelijk worden.

let text;

try {

text = msg.payload.toString('utf8'); // decode bytes

} catch (e) {

text = JSON.stringify(msg.payload); // fallback

}

msg.payload = text;

return msg;

Omdat niet alles naar `UTF-8` omgevormd kan worden (binaire data, transmissiefouten, ...), wordt een fallback-mechanisme gebruikt om de payload alsnog te tonen als `JSON`-data, waardoor debuggen mogelijk blijft.

Dataverwerking `parse_lora_json` voor weergave

Deze functie-node verwerkt de eerder gedecodeerde UART-data en zet deze om naar een object dat eenvoudig te gebruiken is in Node-RED.

De identificatie van het apparaat (`device`) en locatiegegevens (`lat, lon, alt, sats`) worden gebruikt in één overzichtelijke object die op een dashboard getoond kan worden. Daarnaast wordt de temperatuur (`tempC`) gecontroleerd. Als `tempC` een geldig getal is, wordt deze afgerond op twee cijfers na de komma en opgeslagen voor weergave.

### 1.1.18 Shutdown & Startup

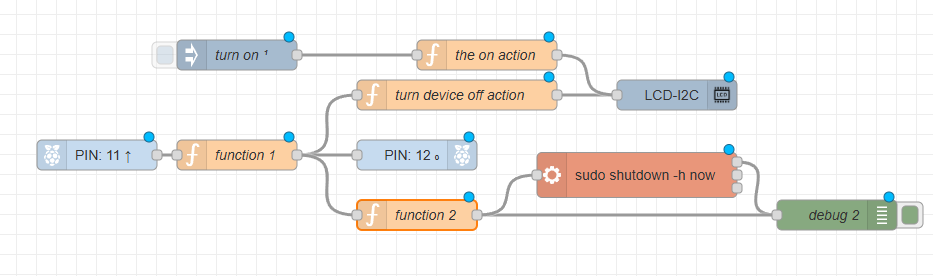
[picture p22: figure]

GPIO 17 (pin 11):

GPIO 17 wordt gebruikt als invoer voor een actief-lage drukknop. Deze knop initieert het afsluitproces.

Eenmalig afsluiten (`function 1`)

Deze oranje function-node zorgt ervoor dat het afsluitproces slechts één keer kan worden geactiveerd. De functie genereert een signaal dat wordt doorgegeven aan alle relevante flows, zodat randapparatuur correct wordt afgesloten voordat het systeem stopt.

GPIO 18 (pin 12):

GPIO 18 wordt gebruikt als uitgang voor een status-LED. De LED geeft aan dat Node-RED correct is afgesloten en dat de Raspberry Pi is uitgeschakeld. De LED is aangesloten via een serieweerstand zodat de LED niet kapot gaat.

Aansturing LCD via I2C

Om de status van het systeem visueel weer te geven, wordt een LCD-scherm via I2C aangestuurd. Hiervoor wordt de Node-RED LCD-I2C library gebruikt.

De LCD-display kan worden uitgeschakeld (`off action`) en ingeschakeld (`on action`) met een function-node:

if(msg.payload == 0){

var msg = {

"action": "off", // vervang "off" door "on" om LCD aan te zetten

};

}

return msg;

Vertraagde systeemafsluiting (`function 2`)

Deze functie initieert de daadwerkelijke uitschakeling van de Raspberry Pi. Hierbij wordt eerst een wachttijd van vijf seconden aangehouden om te garanderen dat alle processen en randapparatuur correct zijn afgesloten.

if(flow.get("power") == 0){

setTimeout(function() {

node.send({ payload: "echo 'Safe test command'" });

}, 5000); // 5s delay

}

Voeg `exec` node (rode node) toe met het command: ```sudo shutdown -h now```

Samenvatting van de shutdown-flow (User Experience)

1. Drukknop wordt ingedrukt
2. Node-RED detecteert het signaal van de drukknop via de GPIO-interface.
3. Eenmalige afsluittrigger wordt geactiveerd. Tijdens deze afsluitprocedure wordt:
  - het LCD-display uitgeschakeld,
  - de LED uitgeschakeld,
  - na een wachttijd van 5 seconden het systeemcommando `shutdown -h now` uitgevoerd.

Samenvatting van de startup-flow (User Experience)

1. Drukknop wordt ingedrukt
2. Raspberry Pi start op via de hardwarematige J2-trigger.
3. Het besturingssysteem en de grafische desktopomgeving van de Raspberry Pi worden geladen.
4. Tijdens het opstartproces wordt het shellscript `nodered_autostart.sh` automatisch uitgevoerd:
  a. Node-RED service wordt herstart om altijd dezelfde beginstatus te garanderen,
  b. na een wachttijd van 5 seconden wordt het Node-RED dashboard automatisch geopend in Chromium in kioskmodus.
5. LCD-display wordt gestart met een éénmalig signaal van het blauwe node `turn on`

# Conclusie

Dit project heeft aangetoond dat een betrouwbaar long-range IoT-communicatiesysteem gerealiseerd kan worden met de LoRa EBYTE E220-modules in combinatie met microcontrollers (ESP32,...) en een centrale ontvanger (Raspberry Pi 5). In de huidige versie wordt Fixed Transmission nog niet toegepast, maar het testen van dit soort communicatie laat zien dat toekomstige implementaties hiervan mogelijk zijn om peer-to-peer-communicatie met gerichte berichten te realiseren en interferentie tussen meerdere nodes te beperken.

De twee prototypes van de verzender laten zien dat zowel het standaardformaat van de ESP32 (50 × 70 mm) als een compactere uitvoering van de Wemos D1 (40 × 60 mm) technisch realiseerbaar zijn. Het compacte ontwerp beter is voor machinale assemblage en het standaardformaat is beter voor handmatige assemblage.

De Raspberry Pi 5 werkt als centrale ontvanger en verwerkingsstation, waarbij Node-RED de visualisatie en dataverwerking van GPS-, temperatuur- en lichtsensorwaarden mogelijk maakt. De combinatie van UART-communicatie, autostart-scripts en veilige in- en uitschakeling zorgt voor een stabiele en gebruiksvriendelijke werking van het systeem.

Samengevat bewijst dit project dat het mogelijk is om betrouwbaar over afstanden groter dan 1 km te verzenden met een modulair LoRa-systeem, waarbij zowel hardware- als softwarecomponenten effectief samenwerken voor een volledig functioneel long-range communicatiesysteem.

# Referentielijst

[1] PXLDIGITAL, Green Project Research Repository, GitHub. [Online]. Beschikbaar: https://github.com/MilanBowz/PXLDIGITAL_GREEN_PROJECT_RESEARCH.git

[2] Ebyte, Ebyte LoRa E220-900T22D – Manual + Config Tool. Ebyte, [Online]. Beschikbaar: https://www.cdebyte.com/products/E220-900T22D/4#Downloads/

[3] Renzo Mischianti, Ebyte LoRa E220 Device – Specificaties en Basisgebruik. Ebyte, [Online]. Beschikbaar: https://mischianti.org/ebyte-lora-e220-llcc68-device-for-arduino-esp32-or-esp8266-specs-and-basic-use-1/ [laatste update: 13 December 2023]

[4] Raspberry Pi Foundation, Enable UART on Raspberry Pi, [Online]. Beschikbaar: https://www.raspberrypi.org/documentation/configuration/uart.md

[5] Arcolinux, https://arcolinux.com/how-to-autostart-any-application-on-any-linux-desktop/

[6] Node-RED, "Getting Started – Local," [Online]. Available: https://nodered.org/docs/getting-started/local

[7] Blackboard PXL, Programming with Node-RED – eBook. Blackboard, [Online]. Beschikbaar: https://blackboard.pxl.be/ultra/courses/_60098_1/outline/file/_2598255_1

Github: PXLDIGITAL_GREEN_PROJECT_RESEARCH 5 / 5

https://www.pxl.be/elektronica-ICT 1 / 5

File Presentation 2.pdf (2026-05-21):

# Elektronische Systemen FSR

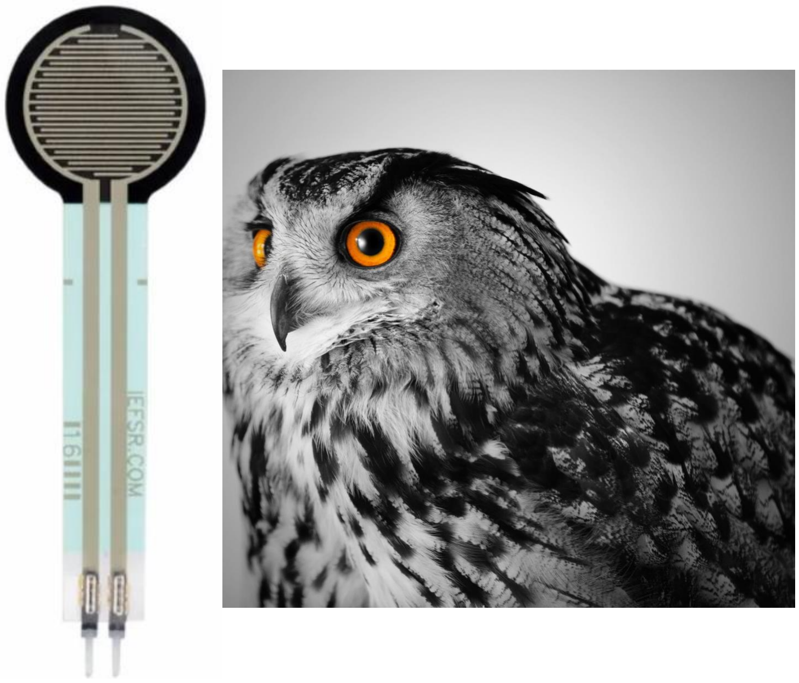
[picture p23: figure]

### FSR sensor

Force-sensing resistors:
- Weerstand verlaagt met kracht

Intern:
- 2 geleidende lagen met daartussen
- drukgevoelig resistief materiaal

## Onderzoeksvraag

“Hoe kan een systeem op basis van FSR-druksensoren worden ontwikkeld en gevalideerd om zithouding (rechtop,onderuitgezakt,...) en bewegingen (verzitten , gewichtsverplaatsing,...) op een stoel te detecteren? ”

## FSR-sensor met pull-down weerstand

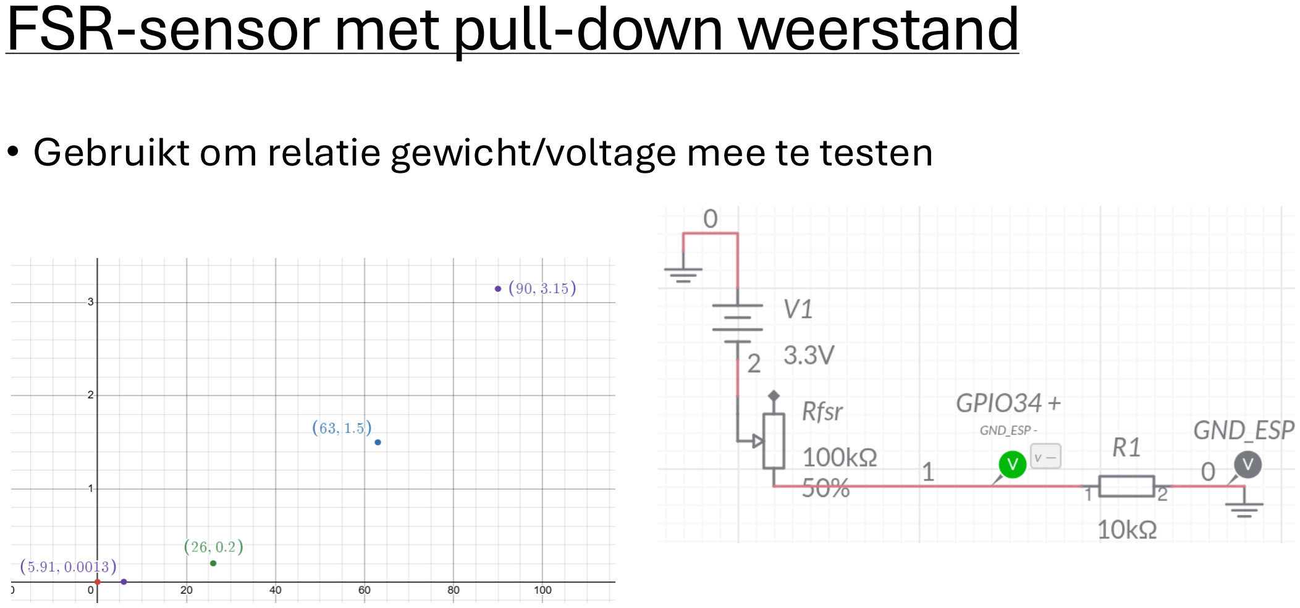
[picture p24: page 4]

- Gebruikt om relatie gewicht/voltage mee te testen

## FSR-sensor met pull-down weerstand


- Vergelijking met theorie

### Demo: FSR data tonen op laptop


## Wat geleerd ? / uitdagingen

- Kiezen voor tijdbesteding / prioriteiten
- Zelfstandig taken opstellen
- Vertrouwbaar testen uitvoeren
- Opstelling / 3D print

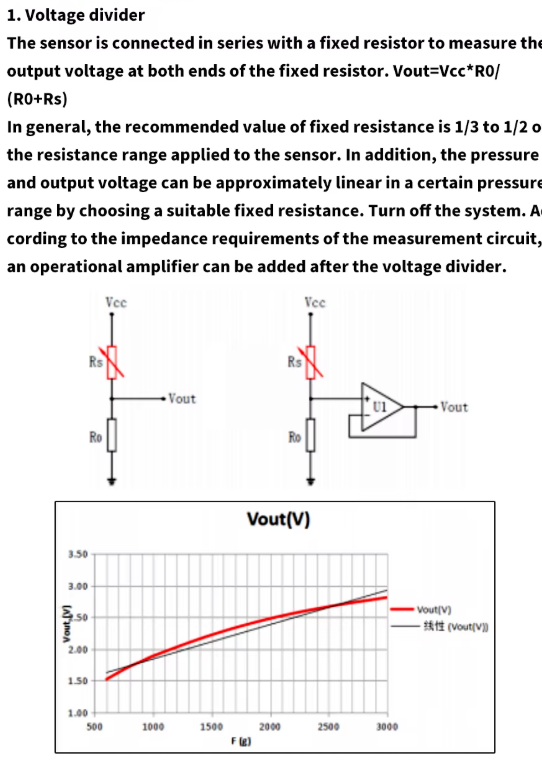
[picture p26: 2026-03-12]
images/FSR_002_basic_voltage_dev.png

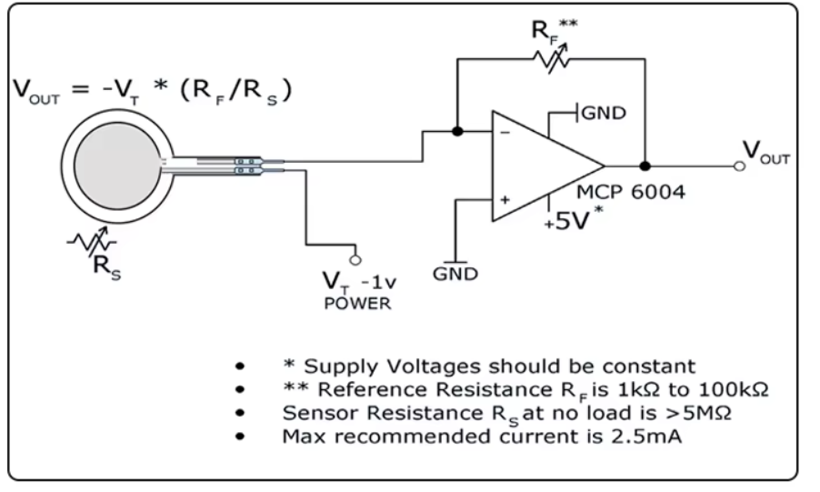
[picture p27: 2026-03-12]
images/FSR_150kg_basic_opamp.png

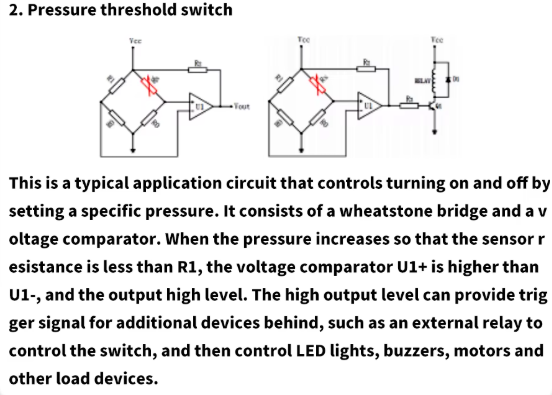
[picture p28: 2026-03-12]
images/FSR_002_basic_brug.png

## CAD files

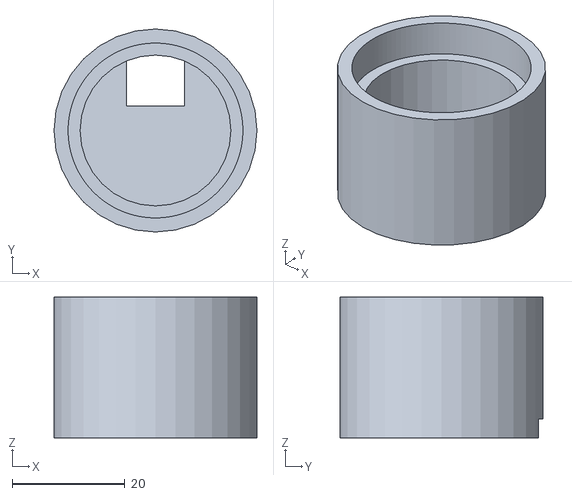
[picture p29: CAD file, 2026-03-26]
3D_prints/Fit_FSR_big_2.stl
36.0 x 36.0 x 25.0

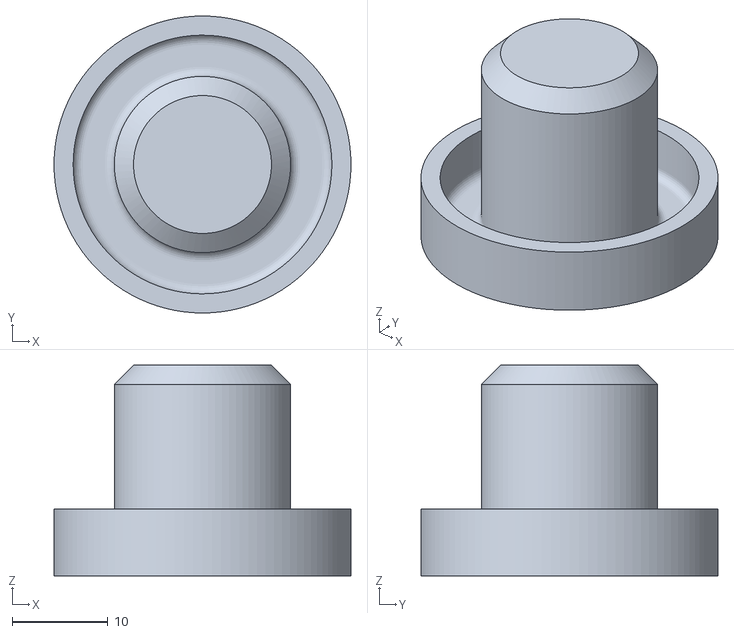
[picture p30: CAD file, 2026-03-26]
3D_prints/Bottle+cap.stl
31.0 x 31.0 x 22.0

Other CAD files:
3D_prints/Untitled.blend

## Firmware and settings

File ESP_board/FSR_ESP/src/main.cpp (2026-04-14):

#include <Arduino.h>
#include "bluetoothHandler.hpp"

// Eenvoudige FSR uitlezing voor ESP32
// Aansluiting: FSR tussen 3.3V en GPIO34, met 10k pull-down weerstand naar GND.

#define FSR_PIN 34          // Gebruik GPIO34/D34 (ADC1_CH6)

// Variabelen voor ruisfiltering
const int numReadings = 10;  // Aantal samples voor middeling
int readings[numReadings];   // Array om samples op te slaan
int readIndex = 0;           // Huidige index in de array
int total = 0;               // Som van alle samples
int average = 0;             // Gemiddelde waarde

// Bluetooth handler
BluetoothHandler bluetooth("ESP32_FSR_Sensor");

// Timing variabelen
unsigned long lastSensorRead = 0;
const int sensorReadInterval = 50; // 50ms = 20Hz

void setup() {
  bluetooth.begin();
  

  // Configureer ADC voor ESP32 voor optimaal bereik (0 - 3.3V)
  analogReadResolution(12);  // 12-bit resolutie (0-4095)
  analogSetAttenuation(ADC_11db);  // Meetbereik 0-3.3V

  // Initialiseer de array voor het filter
  for (int i = 0; i < numReadings; i++) {
    readings[i] = 0;
  }

  bluetooth.printStatus();
}

void loop() {
    // Update Bluetooth status en verwerk inkomende commando's
    bluetooth.update();
    
    // Lees sensor met vaste interval
    if (millis() - lastSensorRead >= sensorReadInterval) {
        lastSensorRead = millis();
        
        // Lees raw ADC waarde
        int rawValue = analogRead(FSR_PIN);
        
        // Voortschrijdend gemiddelde filter
        total = total - readings[readIndex];
        readings[readIndex] = rawValue;
        total = total + readings[readIndex];
        readIndex = (readIndex + 1) % numReadings;
        average = total / numReadings;
        
        // Converteer naar spanning
        // float voltage = (average / 4095.0) * 3.3;
        
        // Verstuur via Bluetooth als verbonden
        bluetooth.sendSensorData((float)rawValue, average);
    }
    // delay(1);
}

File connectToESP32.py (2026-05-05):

# serial_ble_client.py
import serial
import serial.tools.list_ports
import time
import sys
import matplotlib
matplotlib.use('TkAgg')  # Set backend before importing pyplot
import matplotlib.pyplot as plt
import threading
import queue
import warnings
import atexit
import os

warnings.filterwarnings("ignore")  # Suppress all warnings

# Check if plotter exists
try:
    from plotter import SimplePlotter
    TOON_GRAFIEK = True
except ImportError:
    print("Plotter not available, running in text-only mode")
    TOON_GRAFIEK = False

# CONFIGURATION
COM_PORT = "COM22"
BAUD_RATE = 9600

class PlotterThread(threading.Thread):
    """Separate thread for handling the plotter"""
    def __init__(self, max_points=400, window_seconds=8):
        super().__init__()
        self.plotter = None
        self.max_points = max_points
        self.window_seconds = window_seconds
        self.data_queue = queue.Queue(maxsize=1000)
        self.running = True
        self.daemon = True
        self.is_alive_flag = True
        
    def run(self):
        """Run the plotter in a separate thread"""
        try:
            # Suppress warnings in this thread
            import warnings
            warnings.filterwarnings("ignore")
            
            self.plotter = SimplePlotter(
                max_points=self.max_points, 
                window_seconds=self.window_seconds
            )
            
            while self.running and self.plotter and not self.plotter.is_window_closed():
                try:
                    data = self.data_queue.get(timeout=0.05)
                    if data is None:
                        break
                    
                    avg, volt = data
                    if self.plotter:
                        self.plotter.voeg_toe(avg, volt)
                        
                except queue.Empty:
                    if self.plotter:
                        try:
                            # Very short pause
                            plt.pause(0.001)
                        except:
                            pass
                    continue
                    
        except Exception:
            pass  # Silently ignore thread errors
        finally:
            self.is_alive_flag = False
            # Don't try to close plotter here - let main thread handle it
    
    def add_data(self, avg, volt):
        """Add data to the queue"""
        if self.running and self.plotter and not self.plotter.is_window_closed():
            try:
                self.data_queue.put_nowait((avg, volt))
                return True
            except:
                pass
        return False
    
    def is_window_closed(self):
        """Check if window is closed"""
        if self.plotter:
            return self.plotter.is_window_closed()
        return False
    
    def stop(self):
        """Stop the plotter thread"""
        self.running = False
        # Don't close plotter here - let main thread handle it

def find_esp32_com_port():
    """Automatically find ESP32 Bluetooth COM port"""
    ports = serial.tools.list_ports.comports()
    for port in ports:
        if "Bluetooth" in port.description or "Standard Serial" in port.description:
            return port.device
    return None

def cleanup_plotter(plotter_thread):
    """Clean up plotter safely"""
    if plotter_thread:
        try:
            plotter_thread.running = False
            if plotter_thread.plotter:
                # Force close without waiting for thread
                try:
                    plt.close('all')
                except:
                    pass
        except:
            pass
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

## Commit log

2026-03-19 test met ESP32 pure meting
2026-03-26 bestanden 3d model om gewicht te testen
    [Bottle+cap.stl, Fit_FSR_big_2.stl, Untitled.blend]
2026-04-02 grafiek 150kg sensor
2026-04-03 Update Force pressure censor.docx
2026-05-05 aanmaken eindrapport
    [Untitled.blend]
